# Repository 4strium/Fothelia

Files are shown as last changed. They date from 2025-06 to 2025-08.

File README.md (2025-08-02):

<h1 align="center">Fothelia</h1>

<p align="center">
  
  
  <br/>
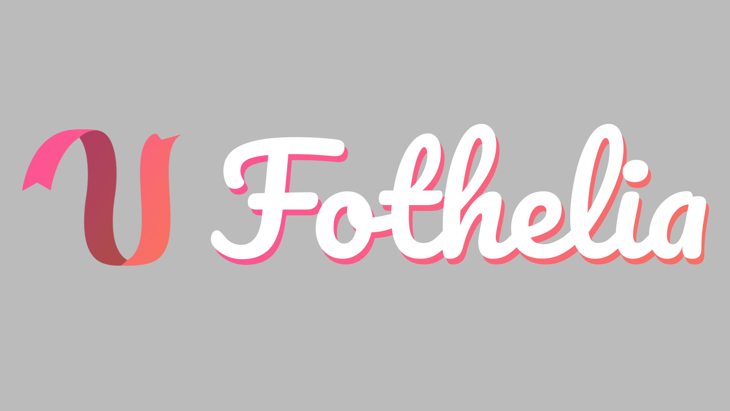
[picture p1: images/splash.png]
Fothelia logo
  
</p>

Fothelia is an ecosystem for controlling LED strips without any internet bridge, just by **Bluetooth** connection.

<p>
  Animated GIF demonstration
</p>

You will need some parts and you're going to need to do a bit of very simple tinkering to take control of the LED strip, but believe me, it will STILL cost you less than buying extension kits — when all you wanted was to use the leftover piece of strip that's been sitting in your closet...

## Building the controller device

By the end your controller device should be looking like this :

<p align='center'>
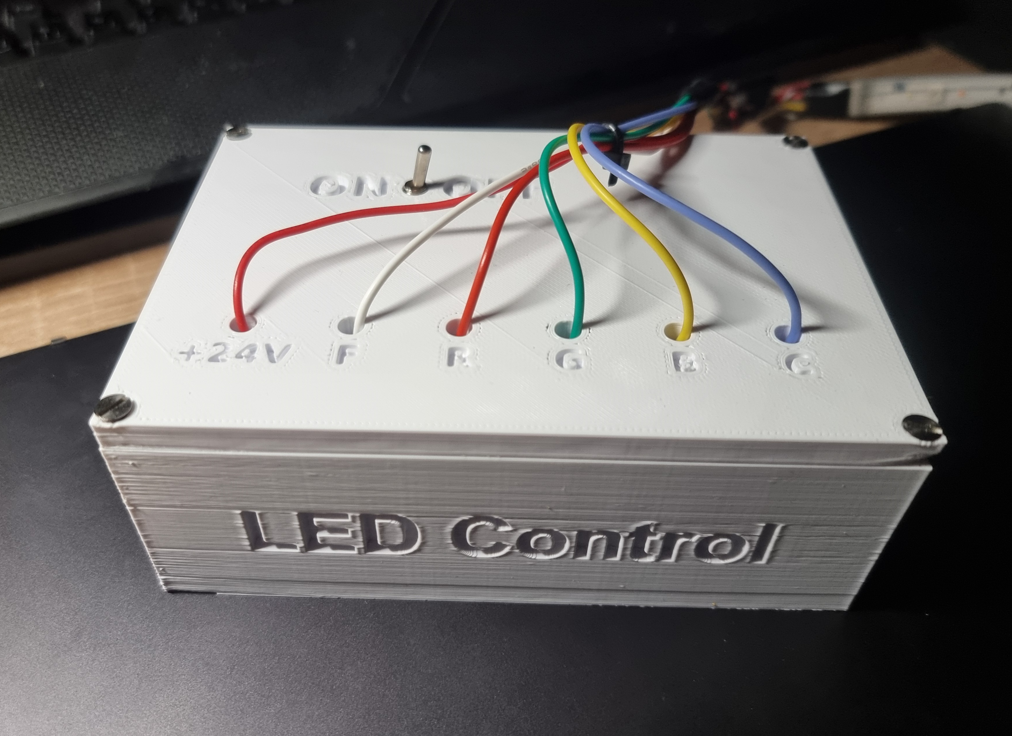
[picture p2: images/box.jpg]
Finished box picture
  
</p>

If you can print the enclosure with a 3D printer, the following CAD project files are available in the [`CAD`](https://github.com/4strium/Fothelia/tree/main/CAD) directory. The box can be big since the `Dollatek LR784 MOSFET Control Module` I am using is huge, thus it is mandatory to provide space inside.

By the way, why use this type of MOSFET and not just cheap MOSFETs? The reason is simple: **Input voltage of LED strip**. On my side I am using a regular Philips HUE led strip but in fact this led strip works with an input voltage of **24V**, so we need a transistor capable of managing this amount of voltage (typically used in industry), and not the type of MOSFET used in low-voltage electronic circuits.

### Alimentation

Therefore, we will need to have a 24V alimentation in our circuit, on my side I chose to boost the 5V output of the ESP32 to obtain the desired 24V (but there are plenty of other solutions to ensure that). I'm using a DC power step up called `MT3608`, and it is working fine, I don't have any issues with this solution!

### Control using PWM

The goal is now to control the different MOSFETs with PWM of the board you're using. If you look closely at one of the two ends of the ribbon, you will notice that we have six inputs:

- C -> Cold White LED's
- B -> Blue component of RGB LED's
- G -> Green component of RGB LED's
- R -> Red component of RGB LED's
- F -> Warm White LED's
- Vcc -> +24V power

<p align='center'>
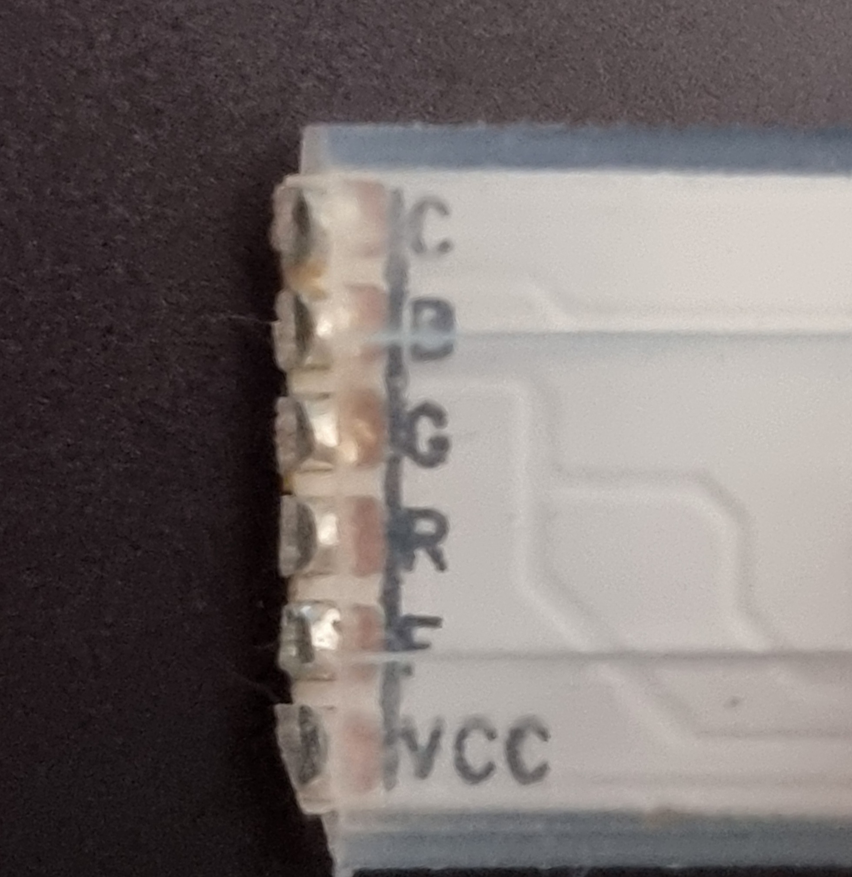
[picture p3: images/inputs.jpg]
LED strip inputs
  
</p>

The alimentation of the MOSFET is +24V and GND of your power source, the load output corresponds to the linear interpolation based on PWM input (with limits: 255 -> GND and 0 -> +24V), thus when the PWM input for the cold white LED MOSFET is equal to 255, then the corresponding LEDs are lit at their maximum power because the F pin is now directly connected to ground, meaning that the difference between the LED strip power source and the F pin is: $24-0=24V$.

I think you understood that with a PWM value of 128, the differential voltage between the power source and the pin is $24-12=12V$ therefore the LEDs are lit at half their maximum power.

You can use any PWM outputs of your development board, just change the value in the `main.cpp` code :

```
#define RED_PIN     13
#define GREEN_PIN   12
#define BLUE_PIN    25
#define COLD_PIN    32
#define WARM_PIN    26
```

Now you just need to wire the different transistors to the PWM outputs of your micro-controller and you should get an assembly like this:

<p align='center'>
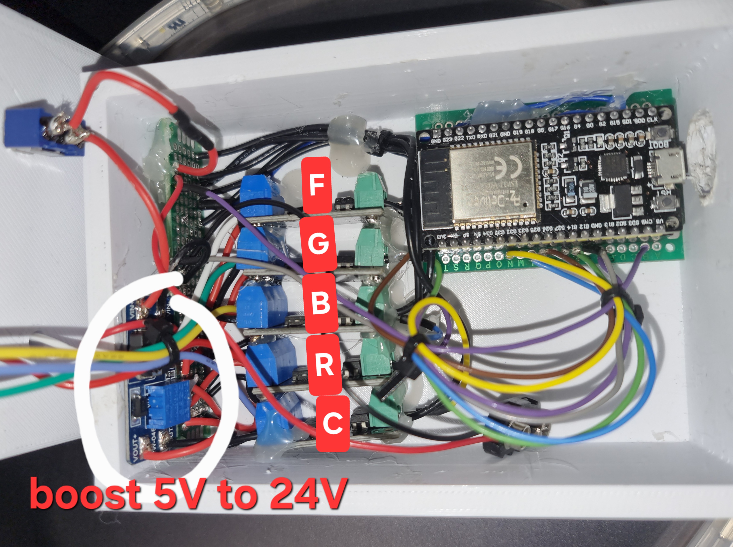
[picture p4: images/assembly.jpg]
Final assembly picture
  
</p>

If everything is properly wired and the program is correctly flashed onto your module, all you need to do is power your board (via USB, jack, etc...). The program should initialize normally without any issues, ready to receive instructions sent by the software, which we will detail in the next section.

## Using the Fothelia Control software

### Requirements

**This section must be followed only by users who want to execute the python script instead of using the executable portable version (available in the releases page).**

The following steps must be accomplished and verified before first use :

1. A proper Python installation to run the `app.py` script.
2. All dependencies installed :

```
pip install PyQt6 pybluez librosa scipy numpy sounddevice
```

### Features

#### Basic Mode

- RGB Mode: control the RGB LEDs by specifying red, green and blue component amount.
- Cool White Mode: control the Cool White LEDs by specifying the power of LEDs (0 to 255).
- Warm White Mode: control the Warm White LEDs by specifying the power of LEDs (0 to 255).

#### Disco Mode

- Wave Color: An infinite gradient of colors cycling through the entire color spectrum.
- Music SYNC: Give an .mp3 file of your favorite music and the light strip will display the perfect color (or flashing white) matching the dominant frequency each 100ms. The app plays synchronously the sound in background on your speakers.

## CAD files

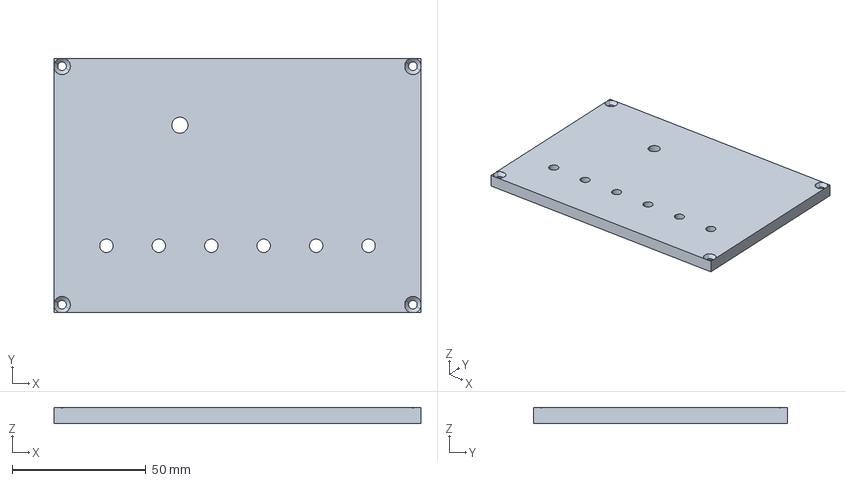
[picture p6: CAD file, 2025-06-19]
CAD/CouvercleBoitierLED.igs
137.0 x 95.0 x 6.00 mm

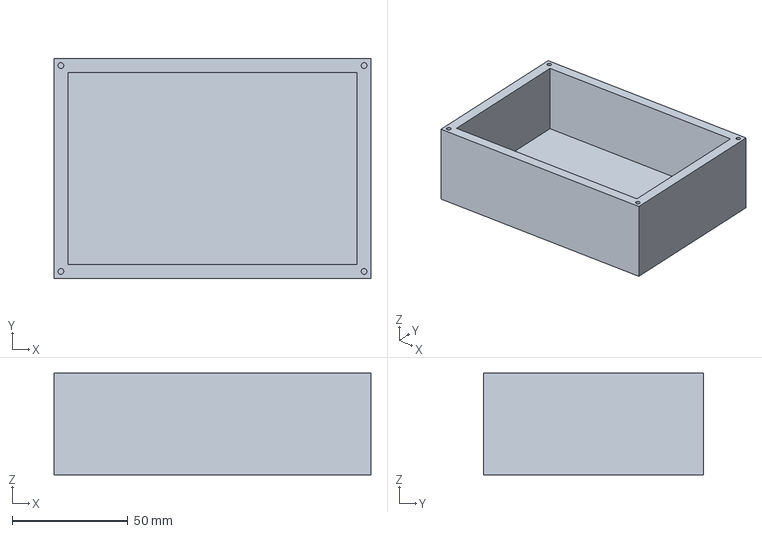
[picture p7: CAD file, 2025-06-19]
CAD/BoitierExt.igs
137.0 x 95.0 x 44.0 mm

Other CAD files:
CAD/BoitierExt.3mf
CAD/CouvercleBoitierLED.CATPart

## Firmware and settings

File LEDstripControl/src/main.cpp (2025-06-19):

#include <Arduino.h>
#include <BluetoothSerial.h>

#if !defined(CONFIG_BT_ENABLED) || !defined(CONFIG_BLUEDROID_ENABLED)
#error Bluetooth is not enabled! Please run `make menuconfig` to and enable it
#endif

BluetoothSerial SerialBT;

// Définition des broches
#define RED_PIN     13
#define GREEN_PIN   12
#define BLUE_PIN    25
#define COLD_PIN    32
#define WARM_PIN    26

// Définition des canaux PWM (0–15)
#define RED_CH      0
#define GREEN_CH    1
#define BLUE_CH     2
#define COLD_CH     3
#define WARM_CH     4

void setup() {
  // Initialisation des canaux PWM (fréquence de 5 kHz, résolution 8 bits)
  ledcSetup(RED_CH, 5000, 8);
  ledcSetup(GREEN_CH, 5000, 8);
  ledcSetup(BLUE_CH, 5000, 8);
  ledcSetup(COLD_CH, 5000, 8);
  ledcSetup(WARM_CH, 5000, 8);

  // Attacher chaque broche à un canal PWM
  ledcAttachPin(RED_PIN, RED_CH);
  ledcAttachPin(GREEN_PIN, GREEN_CH);
  ledcAttachPin(BLUE_PIN, BLUE_CH);
  ledcAttachPin(COLD_PIN, COLD_CH);
  ledcAttachPin(WARM_PIN, WARM_CH);

  Serial.begin(115200);
  SerialBT.begin("LEDstrip");
}

void decodeFrame(String frame){
  int r = 0, g = 0, b = 0, c = 0, w = 0;
  int idxR = frame.indexOf("'R': '");
  int idxG = frame.indexOf("'G': '");
  int idxB = frame.indexOf("'B': '");
  int idxC = frame.indexOf("'C': '");
  int idxW = frame.indexOf("'W': '");

  if (idxR != -1) {
    int endR = frame.indexOf("'", idxR + 6);
    String rStr = frame.substring(idxR + 6, endR);
    r = rStr.toInt();
  }
  if (r > 255 || r < 0) r = 0;
  if (idxG != -1) {
    int endG = frame.indexOf("'", idxG + 6);
    String gStr = frame.substring(idxG + 6, endG);
    g = gStr.toInt();
  }
  if (g > 255 || g < 0) g = 0;
  if (idxB != -1) {
    int endB = frame.indexOf("'", idxB + 6);
    String bStr = frame.substring(idxB + 6, endB);
    b = bStr.toInt();
  }
  if (b > 255 || b < 0) b = 0;
  if (idxC != -1) {
    int endC = frame.indexOf("'", idxC + 6);
    String cStr = frame.substring(idxC + 6, endC);
    c = cStr.toInt();
  }
  if (c > 255 || c < 0) c = 0;
  if (idxW != -1) {
    int endW = frame.indexOf("'", idxW + 6);
    String wStr = frame.substring(idxW + 6, endW);
    w = wStr.toInt();
  }
  if (w > 255 || w < 0) w = 0;

  ledcWrite(RED_CH, r);
  ledcWrite(GREEN_CH, g);
  ledcWrite(BLUE_CH, b);
  ledcWrite(COLD_CH, c);
  ledcWrite(WARM_CH, w);
}

void loop() {
  int acc = 0;
  String frameReceived = "";
  if (SerialBT.available()) {
    String input_data = String((char)SerialBT.read());
    if (input_data == "S"){
      while (acc < 120)
      {
        acc++;
        frameReceived += String((char)SerialBT.read());
      }
      decodeFrame(frameReceived);
    }
  }
  delay(10);
}

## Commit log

2025-08-01 Update .gitignore to include LEDstripControl build directory
2025-08-01 Update README with assembly instructions and features
    Expanded the README with detailed assembly instructions, wiring guidance, and added a new section describing the Fothelia Control software requirements and features. Also added an assembly image for 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
